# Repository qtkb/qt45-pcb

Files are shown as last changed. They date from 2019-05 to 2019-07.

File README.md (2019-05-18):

# qt45 keyboard PCB

A single-layout 45-key PCB with a [compatible acrylic layered case](https://github.com/qtkb/qt45-case).

qt45 prototype

## BOM

| LCSC part # | Description | Package  | Value | Reference | Amount |
|---|---|---|---:|---|---:|
| C296091 | Capacitor | 0805 |  22pF | C1, C2 | 2 |
| C128353 | Capacitor | 0805 | 0.1uF | C3-C5 | 3 |
| C89854 | Capacitor | 0805 |  10uF | C6 | 1 |
| C215803 | Capacitor | 0805 | 1uF | C7 | 1 |
| C2099 | Diode | SOD-123  | | D1-D45 | 45 |
| C163512 | Fuse | 1206 | | F1 | 1 |
| C325772 | Resistor | 0805 | 22 | R1, R2 | 2 |
| C103904 | Resistor | 0805 | 10K | R3, R4 | 2 |
| C92584 | Switch | SMD | | | 1 |
| C44854 | MCU | QFP-44 |  32U4 | | 1 |
| C145778 | Connector | SMD | | | 1 |
| C255909 | Crystal | TSX-3225 | 16MHz | Y1 | 1 |

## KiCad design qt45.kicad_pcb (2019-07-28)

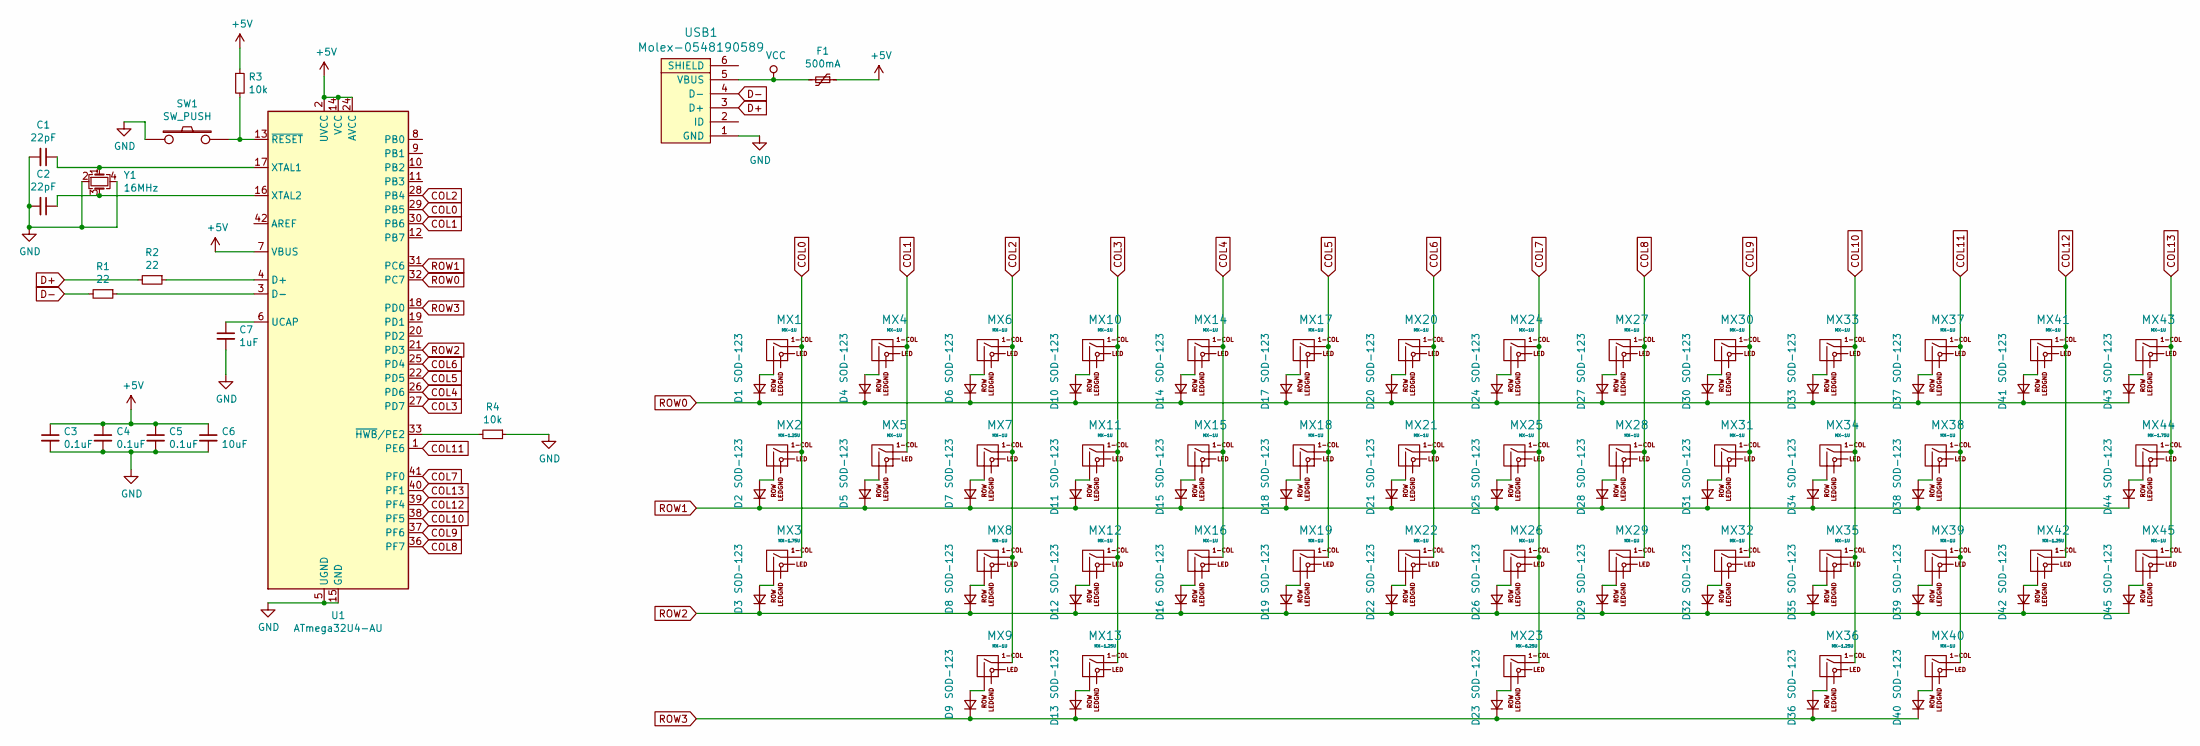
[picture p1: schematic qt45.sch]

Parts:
C1, C2: 22pF; C_0805_2012Metric
C3, C4, C5: 0.1uF; C_0805_2012Metric
C6: 10uF; C_0805_2012Metric
C7: 1uF; C_0805_2012Metric
D1, D2, D3, D4, D5, D6, D7, D8, D9, D10, D11, D12, D13, D14, D15, D16, D17, D18, D19, D20, D21, D22, D23, D24, D25, D26, D27, D28, D29, D30, D31, D32, D33, D34, D35, D36, D37, D38, D39, D40, D41, D42, D43, D44, D45: SOD-123; D_SOD-123-Pretty
F1: 500mA; Fuse_1206_3216Metric
MX1, MX4, MX5, MX6, MX7, MX8, MX9, MX10, MX11, MX12, MX14, MX15, MX16, MX17, MX18, MX19, MX20, MX21, MX22, MX24, MX25, MX26, MX27, MX28, MX29, MX30, MX31, MX32, MX33, MX34, MX35, MX37, MX38, MX39, MX40, MX41, MX43, MX45: MX-1U; MXOnly-1U-NoLED
MX2, MX13, MX36, MX42: MX-1.25U; MXOnly-1.25U-NoLED
MX3, MX44: MX-1.75U; MXOnly-1.75U-NoLED
MX23: MX-6.25U; MXOnly-6.25U-ReversedStabilizers-NoLED
R1, R2: 22; R_0805_2012Metric
R3, R4: 10k; R_0805_2012Metric
SW1: SW_PUSH; SKQG-1155865
U1: ATmega32U4-AU; TQFP-44_10x10mm_P0.8mm
USB1: Molex-0548190589
Y1: 16MHz; Crystal_SMD_3225-4Pin_3.2x2.5mm

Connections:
+5V: C3.1, C4.1, C5.1, C6.1, F1.1, R3.1, U1.2 (UVCC), U1.7 (VBUS), U1.14 (VCC), U1.24 (AVCC), U1.34 (VCC), U1.44 (AVCC)
COL0: MX1.1 (COL), MX2.1 (COL), MX3.1 (COL), U1.29 (PB5)
COL1: MX4.1 (COL), MX5.1 (COL), U1.30 (PB6)
COL2: MX6.1 (COL), MX7.1 (COL), MX8.1 (COL), MX9.1 (COL), U1.28 (PB4)
COL3: MX10.1 (COL), MX11.1 (COL), MX12.1 (COL), MX13.1 (COL), U1.27 (PD7)
COL4: MX14.1 (COL), MX15.1 (COL), MX16.1 (COL), U1.26 (PD6)
COL5: MX17.1 (COL), MX18.1 (COL), MX19.1 (COL), U1.22 (PD5)
COL6: MX20.1 (COL), MX21.1 (COL), MX22.1 (COL), U1.25 (PD4)
COL7: MX23.1 (COL), MX24.1 (COL), MX25.1 (COL), MX26.1 (COL), U1.41 (PF0)
COL8: MX27.1 (COL), MX28.1 (COL), MX29.1 (COL), U1.36 (PF7)
COL9: MX30.1 (COL), MX31.1 (COL), MX32.1 (COL), U1.37 (PF6)
COL10: MX33.1 (COL), MX34.1 (COL), MX35.1 (COL), MX36.1 (COL), U1.38 (PF5)
COL11: MX37.1 (COL), MX38.1 (COL), MX39.1 (COL), MX40.1 (COL), U1.1 (PE6)
COL12: MX41.1 (COL), MX42.1 (COL), U1.39 (PF4)
COL13: MX43.1 (COL), MX44.1 (COL), MX45.1 (COL), U1.40 (PF1)
D+: R2.2, USB1.3 (D+)
D-: R1.2, USB1.4 (D-)
GND: C1.2, C2.2, C3.2, C4.2, C5.2, C6.2, C7.2, R4.1, SW1.1, U1.5 (UGND), U1.15 (GND), U1.23 (GND), U1.35 (GND), U1.43 (GND), USB1.1 (GND), Y1.2, Y1.4
unnamed: C1.1, U1.17 (XTAL1), Y1.1
unnamed: C2.1, U1.16 (XTAL2), Y1.3
unnamed: C7.1, U1.6 (UCAP)
unnamed: D1.2 (A), MX1.2 (ROW)
unnamed: D2.2 (A), MX2.2 (ROW)
unnamed: D3.2 (A), MX3.2 (ROW)
unnamed: D4.2 (A), MX4.2 (ROW)
unnamed: D5.2 (A), MX5.2 (ROW)
unnamed: D6.2 (A), MX6.2 (ROW)
unnamed: D7.2 (A), MX7.2 (ROW)
unnamed: D8.2 (A), MX8.2 (ROW)
unnamed: D9.2 (A), MX9.2 (ROW)
unnamed: D10.2 (A), MX10.2 (ROW)
unnamed: D11.2 (A), MX11.2 (ROW)
unnamed: D12.2 (A), MX12.2 (ROW)
unnamed: D13.2 (A), MX13.2 (ROW)
unnamed: D14.2 (A), MX14.2 (ROW)
unnamed: D15.2 (A), MX15.2 (ROW)
unnamed: D16.2 (A), MX16.2 (ROW)
unnamed: D17.2 (A), MX17.2 (ROW)
unnamed: D18.2 (A), MX18.2 (ROW)
unnamed: D19.2 (A), MX19.2 (ROW)
unnamed: D20.2 (A), MX20.2 (ROW)
unnamed: D21.2 (A), MX21.2 (ROW)
unnamed: D22.2 (A), MX22.2 (ROW)
unnamed: D23.2 (A), MX23.2 (ROW)
unnamed: D24.2 (A), MX24.2 (ROW)
unnamed: D25.2 (A), MX25.2 (ROW)
unnamed: D26.2 (A), MX26.2 (ROW)
unnamed: D27.2 (A), MX27.2 (ROW)
unnamed: D28.2 (A), MX28.2 (ROW)
unnamed: D29.2 (A), MX29.2 (ROW)
unnamed: D30.2 (A), MX30.2 (ROW)
unnamed: D31.2 (A), MX31.2 (ROW)
unnamed: D32.2 (A), MX32.2 (ROW)
unnamed: D33.2 (A), MX33.2 (ROW)
unnamed: D34.2 (A), MX34.2 (ROW)
unnamed: D35.2 (A), MX35.2 (ROW)
unnamed: D36.2 (A), MX36.2 (ROW)
unnamed: D37.2 (A), MX37.2 (ROW)
unnamed: D38.2 (A), MX38.2 (ROW)
unnamed: D39.2 (A), MX39.2 (ROW)
unnamed: D40.2 (A), MX40.2 (ROW)
unnamed: D41.2 (A), MX41.2 (ROW)
unnamed: D42.2 (A), MX42.2 (ROW)
unnamed: D43.2 (A), MX43.2 (ROW)
unnamed: D44.2 (A), MX44.2 (ROW)
unnamed: D45.2 (A), MX45.2 (ROW)
unnamed: R1.1, U1.3 (D-)
unnamed: R2.1, U1.4 (D+)
unnamed: R3.2, SW1.2, U1.13 (~RESET)
unnamed: R4.2, U1.33 (~HWB~/PE2)
ROW0: D1.1 (K), D4.1 (K), D6.1 (K), D10.1 (K), D14.1 (K), D17.1 (K), D20.1 (K), D24.1 (K), D27.1 (K), D30.1 (K), D33.1 (K), D37.1 (K), D41.1 (K), D43.1 (K), U1.32 (PC7)
ROW1: D2.1 (K), D5.1 (K), D7.1 (K), D11.1 (K), D15.1 (K), D18.1 (K), D21.1 (K), D25.1 (K), D28.1 (K), D31.1 (K), D34.1 (K), D38.1 (K), D44.1 (K), U1.31 (PC6)
ROW2: D3.1 (K), D8.1 (K), D12.1 (K), D16.1 (K), D19.1 (K), D22.1 (K), D26.1 (K), D29.1 (K), D32.1 (K), D35.1 (K), D39.1 (K), D42.1 (K), D45.1 (K), U1.21 (PD3)
ROW3: D9.1 (K), D13.1 (K), D23.1 (K), D36.1 (K), D40.1 (K), U1.18 (PD0)
VCC: F1.2, USB1.5 (VBUS)

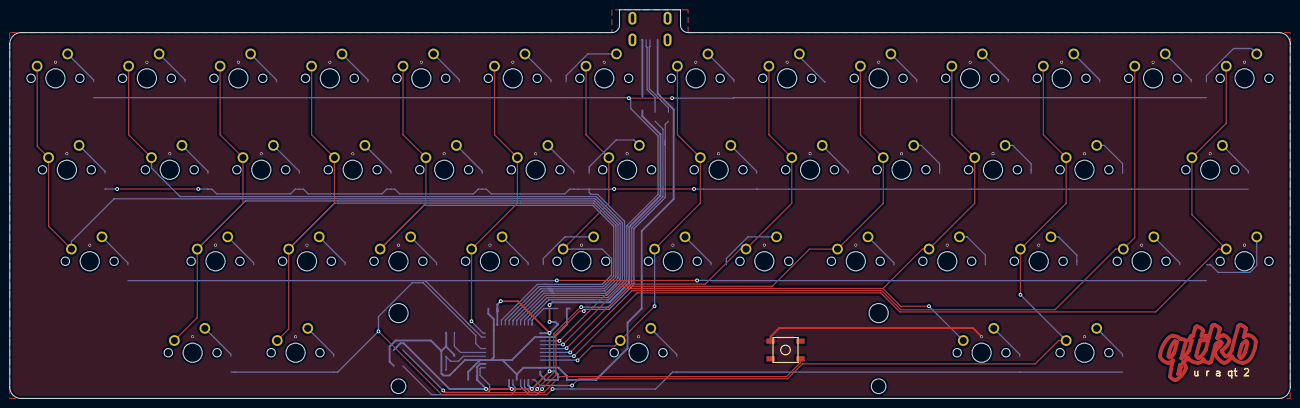
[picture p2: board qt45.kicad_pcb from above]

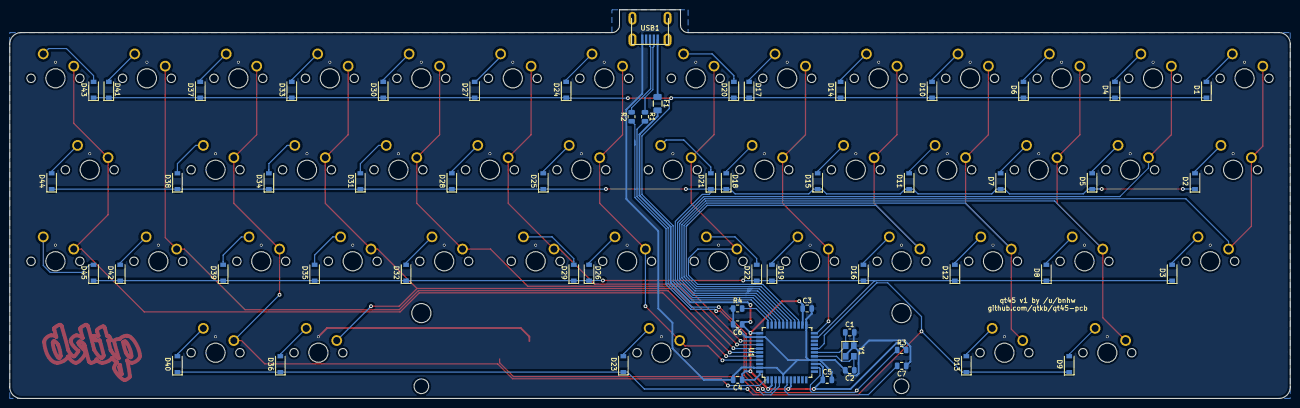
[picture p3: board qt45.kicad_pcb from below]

Board: 2 copper layers, 266.7 x 81.0 mm, 106 parts (60 on the bottom side), 75 nets.

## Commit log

2019-03-26 Create project
    [qt45.kicad_pcb, qt45.sch]
2019-03-26 Draw schematic
2019-03-26 Layout key switches
    [qt45.sch]
2019-03-27 Rough placement of components
    [qt45.kicad_pcb, qt45.sch]
2019-03-27 Route key switches
    [qt45.kicad_pcb]
2019-03-27 Routing (no rows and columns)
    [qt45.kicad_pcb, qt45.sch]
2019-03-27 Routing fixes
    [qt45.kicad_pcb]
2019-03-27 Start reroute
    [qt45.kicad_pcb, qt45.sch]
2019-03-28 More routing
    [qt45.kicad_pcb, qt45.sch]
2019-03-28 First draft of routing
    [qt45.kicad_pcb, qt45.sch]
2019-03-28 Add ground plane
    [qt45.kicad_pcb]
2019-03-28 Re-route to maximise ground plane
    [qt45.kicad_pcb, qt45.sch]
2019-03-28 Config for export
    [qt45.kicad_pcb]
2019-03-30 Create BOM
2019-03-30 Add branding and adjust silkscreen
    [qt45.kicad_pcb]
2019-03-30 Fix some issues
    [qt45.kicad_pcb, qt45.sch]
2019-03-30 Increase size of copper in logo and add version number
    [qt45.kicad_pcb]
2019-03-31 Add connector to BOM
2019-04-17 Choose a diode that will actually fit the pads (whoops)
2019-05-18 Reformat BOM and include references
2019-07-28 Add front ground plane
    [qt45.kicad_pcb]
